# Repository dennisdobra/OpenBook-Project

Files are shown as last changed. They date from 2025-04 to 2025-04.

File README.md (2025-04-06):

# 📖 OpenBook ESP32-C6 – Hardware Overview & Pin Connections

This document describes the **hardware functionality**, **pin mappings**, and **key components** of the OpenBook e-reader, based on the ESP32-C6-WROOM-1-N8 microcontroller.

## 🛠️ Implementation Steps

1. **Schematic Design** – Created in Eagle with all key modules (ESP32-C6, RTC, BME688, etc.).

2. **2D PCB Layout** – Components placed with routing efficiency in mind.

3. **Signal Routing** – Manual routing of SPI, I²C, USB; verified differential pairs.

4. **GND Plane** – Full ground pour on both layers for EMI reduction.

5. **Power Net Classes** – Separate nets for VBAT, VUSB, and 3V3 with wider traces.

6. **Custom Rules** – DRC settings for clearance, trace width, via sizes uploaded.

7. **3D Models** – Designed from datasheets for battery, screen, and connectors.

---

## 🔧 Hardware Overview

### 🧠 Main Controller – ESP32-C6-WROOM-1-N8

- **Architecture**: RISC-V (Single-Core)
- **Wireless**: Wi-Fi 6, Bluetooth 5 LE
- **Operating Voltage**: 3.3V
- **Interfaces**: SPI, I²C, UART, GPIO, USB

---

## 💾 Storage & Display

### 📁 SD Card
- **Interface**: SPI
- **Pins**:
  - CS (SS_SD): `GPIO 4`
  - MOSI: `GPIO 7`
  - MISO: `GPIO 2`
  - SCK: `GPIO 6`

### 🖼️ E-Paper Display
- **Interface**: SPI (shared with SD)
- **Pins**:
  - CS (EPD_CS): `GPIO 10`
  - DC (EPD_DC): `GPIO 5`
  - RESET: `GPIO 23`
  - BUSY: `GPIO 3` *(shared with MISO)*
  - MOSI / SCK: shared with SD

### 💾 External NOR Flash (64MB)
- **Interface**: SPI (shared)
- **Pins**:
  - CS (FLASH_CS): `GPIO 12`
  - Shared: `MOSI`, `MISO`, `SCK`

---

## ⏱️ Timekeeping & Sensors

### 🕒 RTC – DS3231SN
- **Interface**: I²C
- **Pins**:
  - SCL: `GPIO 22`
  - SDA: `GPIO 21`
  - INT: `GPIO 8`
  - 32KHz: `GPIO 1`
  - RESET: `GPIO 18`

### 🌡️ Environmental Sensor – BME688
- **Interface**: I²C (shared with RTC)
- **Supply Voltage**: 3.3V

---

## 🔋 Power Management

### ⚡ Power Supply
- **Input**: USB-C (5V)
- **Output**: 3.3V via LDO regulator
- **Protections**:
  - Reverse polarity diode
  - TVS diodes on USB & SPI lines

### 🔌 Charging Circuit – TP4056
- **Function**: Li-Po battery charging
- **Battery Monitoring**:
  - Gauge via I²C
  - Pins: `GPIO 19` (SCL), `GPIO 20` (SDA)

---

## 🖧 Communication & Interfaces

### 🔌 USB-C Connector
- **Data Pins**:
  - USB_D+: `GPIO 13`
  - USB_D-: `GPIO 12` *(shared with FLASH_CS)*

### 🔗 Qwiic / Stemma QT Connector
- **Interface**: I²C
- **Usage**: Plug-and-play I²C sensors

---

## ⏺️ User Inputs

- **BOOT Button**: `GPIO 9`
- **RESET Button**: connected to EN pin
- **CHANGE Button**: `GPIO 23`

---

## 🛡️ Protection Features

- TVS diodes on:
  - USB data lines
  - SPI lines (SD, Flash, Display)
- Diode-based reverse polarity protection

---

## 🧩 Communication Overview

| Peripheral | Interface | GPIO Pins Used |
|---|---|---|
| SD Card | SPI | GPIO 2, 4, 6, 7 |
| E-Paper Display | SPI | GPIO 3, 5, 10, 23 |
| External NOR Flash | SPI | GPIO 12, shared MOSI/MISO/SCK |
| RTC + BME688 | I²C | GPIO 1, 8, 18, 21, 22 |
| Battery Gauge | I²C | GPIO 19 (SCL), GPIO 20 (SDA) |
| USB-C Data | USB | GPIO 12 (D-), GPIO 13 (D+) |
| Buttons | GPIO | GPIO 9 (BOOT), GPIO 23 (CHANGE), EN |

---

## 📦 Bill of Materials (BOM)

| Componenta | Link | Preț estimativ |
|---|---|---|
| CHG_LED | [KP-1608SURCK - Kingbright](https://www.snapeda.com/parts/KP-1608SURCK/Kingbright/view-part/?ref=search&t=LED%200603) | 0.15€ |
| SJ1 | [Solder Jumpers](https://grabcad.com/library/solder-jumpers-1) | 0.05€ |
| R3 | [R0402 1% 100K (RC0402FR-07100KL) - YAGEO](https://componentsearchengine.com/part-view/R0402%201%25%20100%20K%20(RC0402FR-07100KL)/YAGEO) | 0.01€ |
| R1_PWRUSB | [R0402 1% 100K (RC0402FR-07100KL) - YAGEO](https://componentsearchengine.com/part-view/R0402%201%25%20100%20K%20(RC0402FR-07100KL)/YAGEO) | 0.01€ |
| C1, C2, C4_USB, C6, C7, C8, C9, C10, C_DELAY | [CC0402MRX5R5BB106 - YAGEO](https://componentsearchengine.com/part-view/CC0402MRX5R5BB106/YAGEO) | 0.10€ (per unitate) |
| C3 | [Link 3D model](https://a360.co/4iZy6AA) | 0.12€ |
| R1_PINH1, R2-PINH1, R_BOOT, R_CHARGE, R_CL1, R_RESET | [R0402 1% 100K (RC0402FR-07100KL) - YAGEO](https://componentsearchengine.com/part-view/R0402%201%25%20100%20K%20(RC0402FR-07100KL)/YAGEO) | 0.01€ (per unitate) |
| R1, R1-PINH, R2-PINH, R4, R5, R6, R7, R8, R9, R10 | [R0402 1% 100K (RC0402FR-07100KL) - YAGEO](https://componentsearchengine.com/part-view/R0402%201%25%20100%20K%20(RC0402FR-07100KL)/YAGEO) | 0.01€ (per unitate) |
| J4 | [Store Comet SRL](https://store.comet.srl.ro/Catalogue/Product/43497/) | 0.35€ |
| R_CAPACITOR | [R0402 1% 100K (RC0402FR-07100KL) - YAGEO](https://componentsearchengine.com/part-view/R0402%201%25%20100%20K%20(RC0402FR-07100KL)/YAGEO) | 0.01€ |
| C5 | [CC0402MRX5R5BB106 - YAGEO](https://componentsearchengine.com/part-view/CC0402MRX5R5BB106/YAGEO) | 0.10€ |
| EPD_C1, EPD_C2, EPD_C5, EPD_C6, EPD_C7, EPD_C8, EPD_C9, EPD_C10, EPD_C11, EPD_C12 | [CC0402MRX5R5BB106 - YAGEO](https://componentsearchengine.com/part-view/CC0402MRX5R5BB106/YAGEO) | 0.10€ (per unitate) |
| R2 | [R0402 1% 100K (RC0402FR-07100KL) - YAGEO](https://componentsearchengine.com/part-view/R0402%201%25%20100%20K%20(RC0402FR-07100KL)/YAGEO) | 0.01€ |
| R1_BAT | [R0402 1% 100K (RC0402FR-07100KL) - YAGEO](https://componentsearchengine.com/part-view/R0402%201%25%20100%20K%20(RC0402FR-07100KL)/YAGEO) | 0.01€ |
| Q1, Q3 | [SI1308EDL-T1-GE3 - Vishay](https://componentsearchengine.com/part-view/SI1308EDL-T1-GE3/Vishay) | 0.45€ (per unitate) |
| R2_BAT | [R0402 1% 100K (RC0402FR-07100KL) - YAGEO](https://componentsearchengine.com/part-view/R0402%201%25%20100%20K%20(RC0402FR-07100KL)/YAGEO) | 0.01€ |
| C1_BAT, C1_BAT1, C1_BAT2, C2_BAT, C5_USB | [CC0402MRX5R5BB106 - YAGEO](https://componentsearchengine.com/part-view/CC0402MRX5R5BB106/YAGEO) | 0.10€ (per unitate) |
| C4 | [CC0402MRX5R5BB106 - YAGEO](https://componentsearchengine.com/part-view/CC0402MRX5R5BB106/YAGEO) | 0.10€ |
| R2-USB, R2-USB1 | [R0402 1% 100K (RC0402FR-07100KL) - YAGEO](https://componentsearchengine.com/part-view/R0402%201%25%20100%20K%20(RC0402FR-07100KL)/YAGEO) | 0.01€ (per unitate) |
| L1 | [744043680 - Wurth Elektronik](https://eu.mouser.com/ProductDetail/Wurth-Elektronik/744043680?qs=PGXP4M47uW6VkZq%252BkzjrHA%3D%3D) | 0.85€ |
| IC1 | [BD5229G-TR - ROHM Semiconductor](https://componentsearchengine.com/part-view/BD5229G-TR/ROHM%20Semiconductor) | 1.20€ |
| BOOT_BUTTON, CHANGE_BUTTON, RESET_BUTTON | [EVQP7L01P - Panasonic](https://www.snapeda.com/parts/EVQP7L01P/Panasonic/view-part/?ref=search&t=evqp7l) | 0.25€ (per unitate) |
| C10_SUPERCAP | [CPH3225A - Seiko Instruments](https://www.snapeda.com/api/url_track_click_mouser/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) | 2.50€ |
| U3 | [DS3231SN - Analog Devices](https://www.snapeda.com/api/url_track_click_mouser/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) | 8.95€ |
| U2 | [ESP32-C6-WROOM-1-N8 - Espressif](https://www.snapeda.com/parts/ESP32-C6-WROOM-1-N8/Espressif+Systems/view-part/?ref=eda) | 4.50€ |
| PFMF.050.1 | [B72520T0350K062 - EPCOS-TDK](https://www.mouser.co.uk/ProductDetail/EPCOS-TDK/B72520T0350K062?qs=dEfas%2FXlABIszF52uu7vrg%3D%3D) | 0.65€ |
| D2, D7 | [SD0805S020S1R0 - KYOCERA-AVX](https://eu.mouser.com/ProductDetail/KYOCERA-AVX/SD0805S020S1R0?qs=jCA%252BPfw4LHbpkAoSnwrdjw%3D%3D) | 0.30€ (per unitate) |
| SENSOR2 | [BME680 - Bosch](https://www.snapeda.com/parts/BME680/Bosch/view-part/?welcome=home) | 10.50€ |
| MCP73831 | [MCP73831T-2ACI-OT - Microchip](https://www.digikey.ro/en/products/detail/microchip-technology/MCP73831T-2ACI-OT/964301) | 0.75€ |
| J1 | [XC6220A331MR-G - Torex](https://componentsearchengine.com/part-view/XC6220A331MR-G/Torex) | 1.25€ |
| U4 | [MAX17048G+T10 - Analog Devices](https://www.snapeda.com/api/url_track_click_mouser/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) | 3.80€ |
| D3, D4, D5 | [MBR0530 - ON Semiconductor](https://www.snapeda.com/api/url_track_click_mouser/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) | 0.40€ (per unitate) |
| D6, D8, D9, D10, D11, D12 | [PGB1010603MR - Littelfuse](https://www.snapeda.com/api/url_track_click_mouser/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) | 0.30€ (per unitate) |
| J3 | [Model Link - DigiKey](https://www.digikey.ro/en/models/926710) | 1.05€ |
| J2 | [USB4110-GF-A - GCT](https://componentsearchengine.com/part-view/USB4110-GF-A/GCT%20(GLOBAL%20CONNECTOR%20TECHNOLOGY)) | 0.95€ |
| Q2 | [DMG2305UX-7 - Diodes Inc](https://componentsearchengine.com/part-view/DMG2305UX-7/Diodes%20Incorporated) | 0.55€ |
| TP1, TP2, TP3, TP4, TP5, TP6, TP7, TP8, TP9, TP10, TP11, TP12, TP13, TP14, TP15, TP16, TP17 | [Test Points PCB](https://grabcad.com/library/test-points-printed-circuit-board-1) | 0.02€ (per unitate) |
| D1 | [USBLC6-2SC6Y - STMicroelectronics](https://www.snapeda.com/parts/USBLC6-2SC6Y/STMicroelectronics/view-part/?ref=eda) | 0.60€ |
| U1 | [W25Q512JVEIQ - Winbond](https://www.snapeda.com/parts/W25Q512JVEIQ/Winbond+Electronics/view-part/?ref=eda) | 4.20€ |
| IC4 | [XC6220A331MR-G - Torex](https://componentsearchengine.com/part-view/XC6220A331MR-G/Torex) | 1.25€ |

## 📌 Pin Assignments

| ESP32-C6 Pin | Function | Connected To | Description |
|---|---|---|---|
| 3 | RESET | Reset Button | System hardware reset |
| 4 | SS_SD | SD Card (pin 2) | SPI Slave Select for SD card |
| 6 | SCK | SD Card (pin 5) | SPI Clock signal |
| 7 | MOSI | SD Card (pin 3) | SPI Master Out Slave In |
| 8 | INT_RTC | RTC Module (pin 3) | Interrupt signal from RTC |
| 9 | 32KHz | RTC Module (pin 1) | 32KHz clock signal from RTC |
| 13 | USB_D- | USB-C Connector (pin 3) | USB Data Negative line |
| 14 | USB_D+ | USB-C Connector (pin 1) | USB Data Positive line |
| 15 | IO/BOOT | Boot Button | Boot mode selector button |
| 16 | RTC_RST | RTC Module (pin 4) | RTC reset control |
| 17 | I2C_PW | BME688 Sensor (pins 6, 8, 2) | Power control for environmental sensor |
| 19 | SDA | Multiple I²C devices | I²C Serial Data line (shared) |
| 20 | SCL | Multiple I²C devices | I²C Serial Clock line (shared) |
| 23 | IO/CHANGE | Change Button | Display/Mode change button |
| 27 | MISO | SD Card (pin 7) | SPI Master In Slave Out |

---

# Circuit Block Diagram

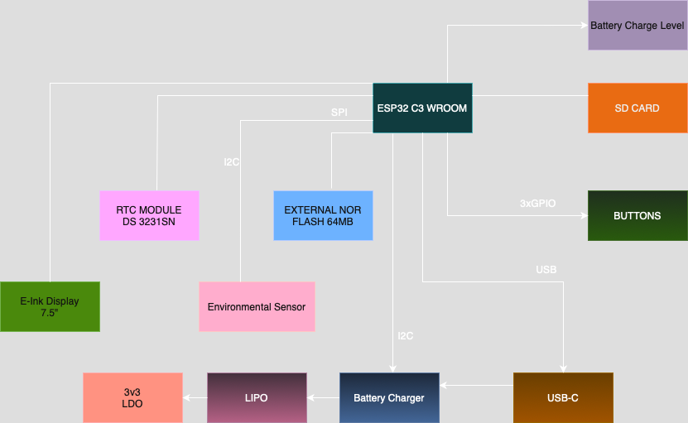
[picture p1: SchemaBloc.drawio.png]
Circuit Block Diagram


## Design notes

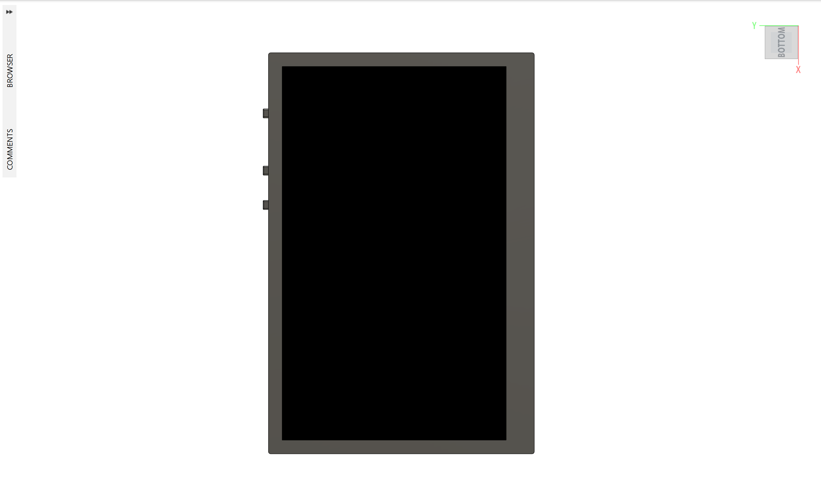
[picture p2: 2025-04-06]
Images/Display1.png

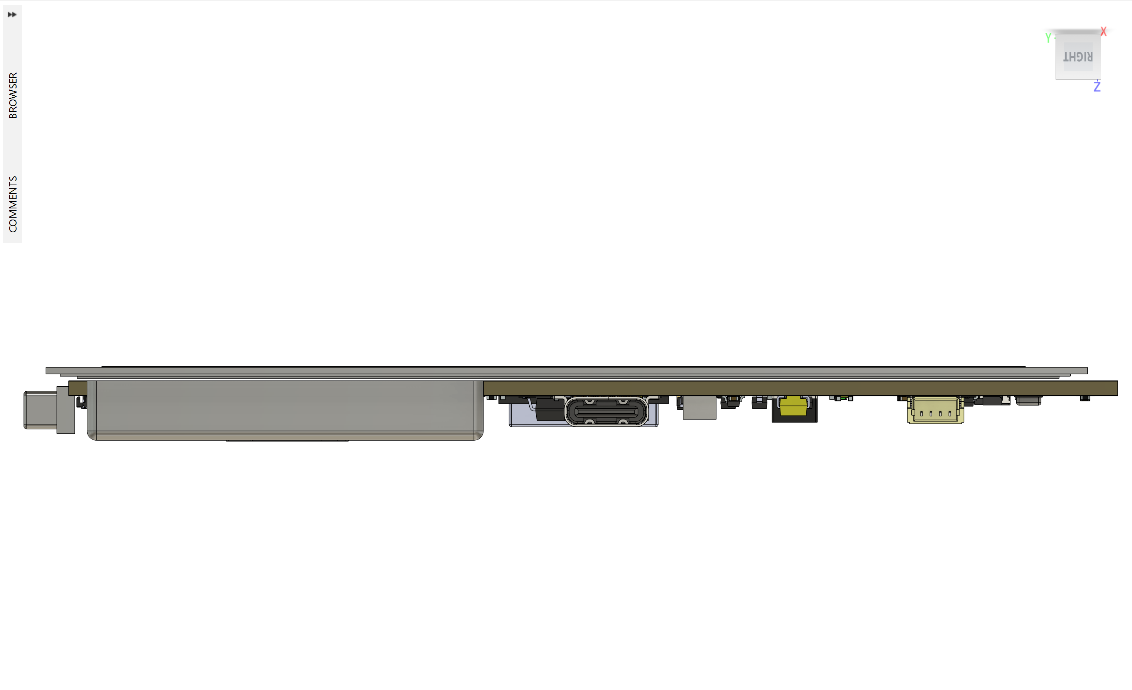
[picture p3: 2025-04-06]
Images/Side_View1.png

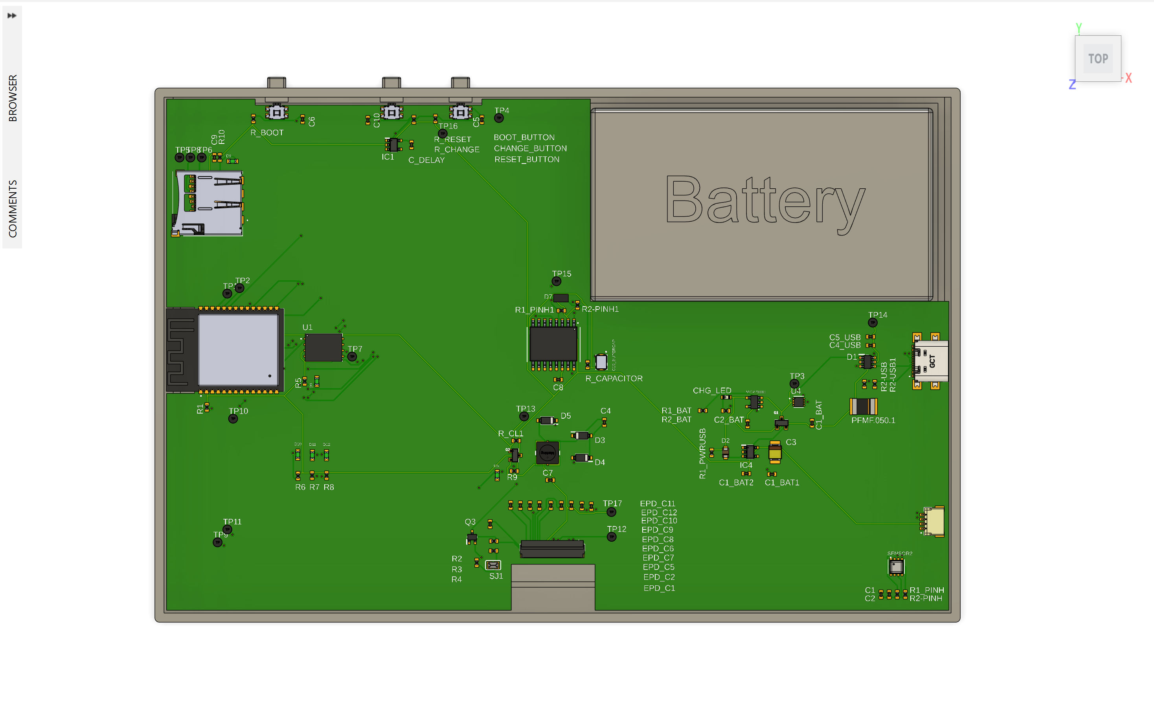
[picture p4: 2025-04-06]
Images/Board1.png

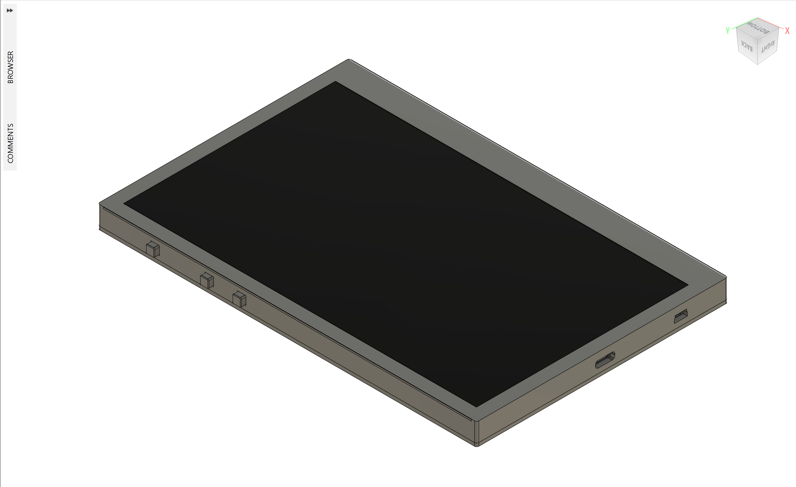
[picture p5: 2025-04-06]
Images/Display2.png

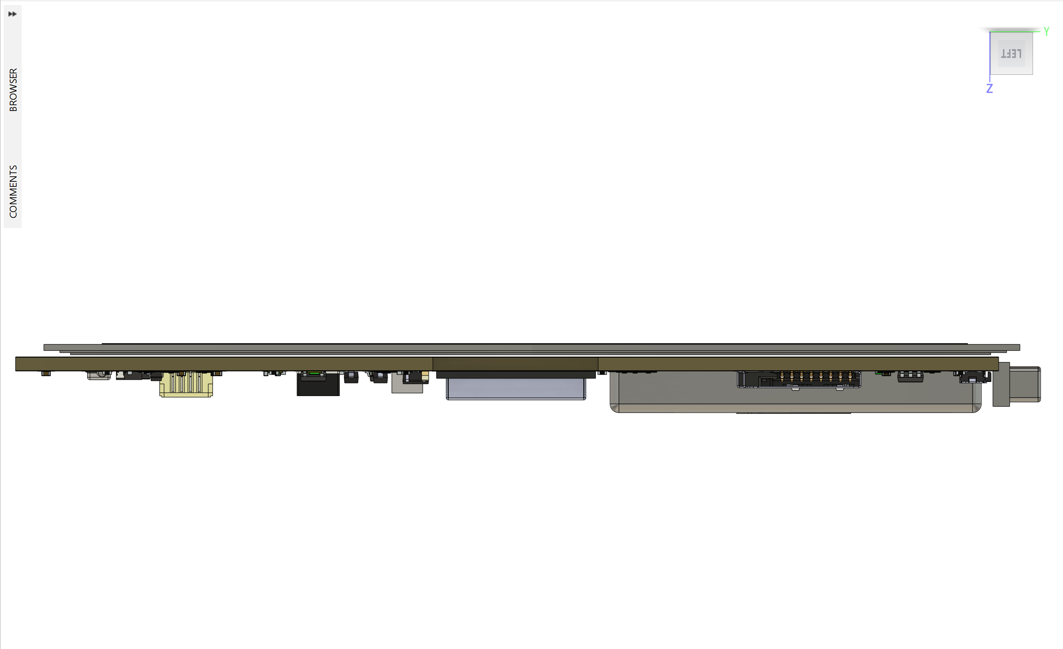
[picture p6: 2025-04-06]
Images/Side_View2.png

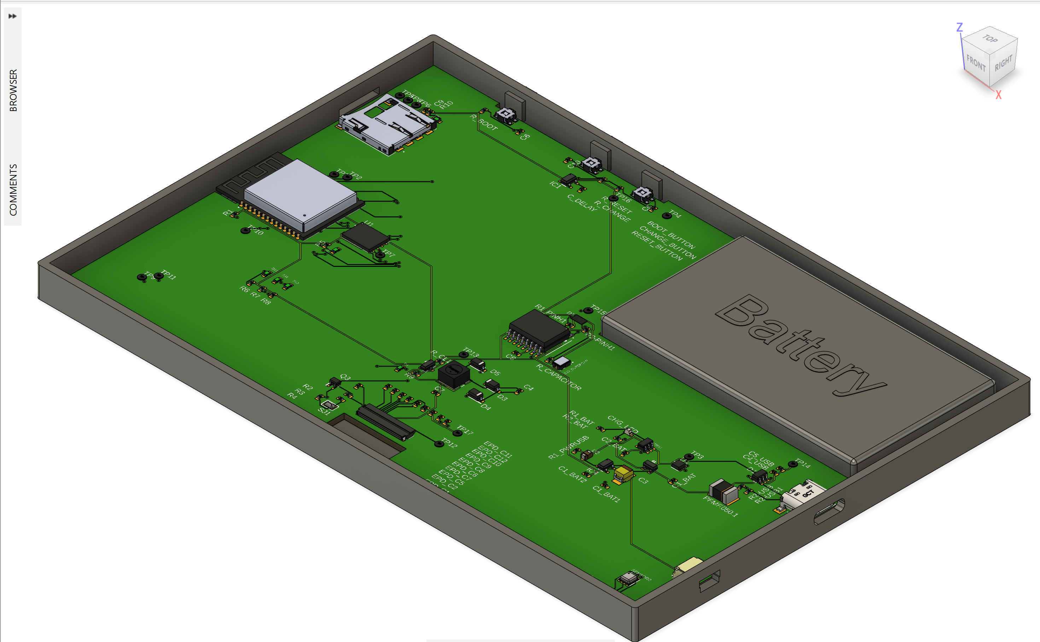
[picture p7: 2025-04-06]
Images/Board2.png

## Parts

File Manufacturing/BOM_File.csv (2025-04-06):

Qty | Value | Device | Package | Parts | Description | ARROW_PART_NUMBER | ARROW_PRICE-STOCK | AVAILABILITY | CENTROID_NOT_SPECIFIED | CHECK_PRICES | COPYRIGHT | DATASHEET | DESCRIPTION | DIGIKEY_DESCRIPTION | DIGIKEY_PART_NUMBER | HEIGHT | LEAD_FREE | MANUFACTURER_NAME | MANUFACTURER_PART_NUMBER | MF | MFR_NAME | MOUSER_PART_NUMBER | MOUSER_PRICE-STOCK | MOUSER_TESTING_PART_NUMBER | MOUSER_TESTING_PRICE-STOCK | MP | MPN | PACKAGE | POPULARITY | PREFIX | PRICE | PROD_ID | PURCHASE-URL | ROHS | SNAPEDA_LINK | SPICEMODEL | SPICEPREFIX | TEMPERATURE_RANGE_HIGH | TEMPERATURE_RANGE_LOW | TP_SIGNAL_NAME | VALUE,,,,,,,,,,,,,,,,
1 |  | ADAFRUIT_LEDCHIP-LED0603 | ADAFRUIT_CHIP-LED0603 | CHG_LED | LED |  |  |  |  |  |  |  |  |  |  |  |  |  |  |  |  |  |  |  |  |  |  |  |  |  |  |  |  |  | https://www.snapeda.com/parts/KP-1608SURCK/Kingbright/view-part/?ref=search&t=LED%200603 |  |  |  |  |  | ,,,,,,,,,,,,,,,,
1 |  | SJ | SJ | SJ1 | SMD solder JUMPER |  |  |  |  |  |  |  |  |  |  |  |  |  |  |  |  |  |  |  |  |  |  |  | 3 |  |  |  | https://grabcad.com/library/solder-jumpers-1 |  |  |  |  |  |  |  | ,,,,,,,,,,,,,,,,
1 | 0.47 | ESP32_WROVER_EAGLE-LTSPICE_RR0402 | ESP32_WROVER_EAGLE-LTSPICE_R0402 | R3 | RESISTOR, European symbol |  |  |  |  |  |  |  |  |  |  |  |  |  |  |  |  |  |  |  |  |  |  |  |  |  |  |  | https://componentsearchengine.com/part-view/R0402%201%25%20100%20K%20(RC0402FR-07100KL)/YAGEO |  |  | NONE | R |  |  |  | ,,,,,,,,,,,,,,,
1 | 100k | ESP32_WROVER_EAGLE-LTSPICE_RR0402 | ESP32_WROVER_EAGLE-LTSPICE_R0402 | R1_PWRUSB | RESISTOR, European symbol |  |  |  |  |  |  |  |  |  |  |  |  |  |  |  |  |  |  |  |  |  |  |  |  |  |  |  | https://componentsearchengine.com/part-view/R0402%201%25%20100%20K%20(RC0402FR-07100KL)/YAGEO |  |  | NONE | R |  |  |  | ,,,,,,,,,,,,,,,
9 | 100nF | EAGLE-LTSPICE_CC0402 | EAGLE-LTSPICE_C0402 | C1, C2, C4_USB, C6, C7, C8, C9, C10, C_DELAY | CAPACITOR, European symbol |  |  |  |  |  |  |  |  |  |  |  |  |  |  |  |  |  |  |  |  |  |  |  |  |  |  |  | https://componentsearchengine.com/part-view/CC0402MRX5R5BB106/YAGEO |  |  | NONE | C |  |  |  | ,,,,,,,
1 | 100uF TANT | RCL_CPOL-EUCT3528 | RCL_CT3528 | C3 | POLARIZED CAPACITOR, European symbol |  |  |  |  |  |  |  |  |  |  |  |  |  |  |  |  |  |  |  |  |  |  |  | 0 |  |  |  | https://a360.co/4iZy6AA |  |  |  | C |  |  |  | ,,,,,,,,,,,,,,,
6 | 10K | ESP32_WROVER_EAGLE-LTSPICE_RR0402 | ESP32_WROVER_EAGLE-LTSPICE_R0402 | R1_PINH1, R2-PINH1, R_BOOT, R_CHARGE, R_CL1, R_RESET | RESISTOR, European symbol |  |  |  |  |  |  |  |  |  |  |  |  |  |  |  |  |  |  |  |  |  |  |  |  |  |  |  | https://componentsearchengine.com/part-view/R0402 1% 100 K (RC0402FR-07100KL)/YAGEO |  |  | NONE | R |  |  |  | ,,,,,,,,,,
10 | 10k | ESP32_WROVER_EAGLE-LTSPICE_RR0402 | ESP32_WROVER_EAGLE-LTSPICE_R0402 | R1, R1-PINH, R2-PINH, R4, R5, R6, R7, R8, R9, R10 | RESISTOR, European symbol |  |  |  |  |  |  |  |  |  |  |  |  |  |  |  |  |  |  |  |  |  |  |  |  |  |  |  | https://componentsearchengine.com/part-view/R0402 1% 100 K (RC0402FR-07100KL)/YAGEO |  |  | NONE | R |  |  |  | ,,,,,,
1 | 112A-TAAR-R03_ATTEND | 112A-TAAR-R03_ATTEND | 112ATAARR03ATTEND | J4 | Micro SD Card Socket, Push-Push Type, Top Mount, SMT, H=1.83mm, 10u |  |  |  |  |  |  |  | Micro SD Card Socket | Push-Push Type | Top Mount | SMT | H=1.83mm | 10u |  |  | 1.9mm |  | ATTEND | 112A-TAAR-R03 ATTEND |  |  |  |  |  |  |  |  | https://store.comet.srl.ro/Catalogue/Product/43497/ |  |  |  |  |  |  |  | ,,,,,,,,,,,
1 | 15 | ESP32_WROVER_EAGLE-LTSPICE_RR0402 | ESP32_WROVER_EAGLE-LTSPICE_R0402 | R_CAPACITOR | RESISTOR, European symbol |  |  |  |  |  |  |  |  |  |  |  |  |  |  |  |  |  |  |  |  |  |  |  |  |  |  |  | https://componentsearchengine.com/part-view/R0402%201%25%20100%20K%20(RC0402FR-07100KL)/YAGEO |  |  | NONE | R |  |  |  | ,,,,,,,,,,,,,,,
1 | 1uF | EAGLE-LTSPICE_CC0402 | EAGLE-LTSPICE_C0402 | C5 | CAPACITOR, European symbol |  |  |  |  |  |  |  |  |  |  |  |  |  |  |  |  |  |  |  |  |  |  |  |  |  |  |  | https://componentsearchengine.com/part-view/CC0402MRX5R5BB106/YAGEO |  |  | NONE | C |  |  |  | ,,,,,,,,,,,,,,,
10 | 1uF/50V | ESP32_WROVER_EAGLE-LTSPICE_CC0402 | ESP32_WROVER_EAGLE-LTSPICE_C0402 | EPD_C1, EPD_C2, EPD_C5, EPD_C6, EPD_C7, EPD_C8, EPD_C9, EPD_C10, EPD_C11, EPD_C12 | CAPACITOR, European symbol |  |  |  |  |  |  |  |  |  |  |  |  |  |  |  |  |  |  |  |  |  |  |  |  |  |  |  | https://componentsearchengine.com/part-view/CC0402MRX5R5BB106/YAGEO |  |  | NONE | C |  |  |  | ,,,,,,
1 | 2.2 | ESP32_WROVER_EAGLE-LTSPICE_RR0402 | ESP32_WROVER_EAGLE-LTSPICE_R0402 | R2 | RESISTOR, European symbol |  |  |  |  |  |  |  |  |  |  |  |  |  |  |  |  |  |  |  |  |  |  |  |  |  |  |  | https://componentsearchengine.com/part-view/R0402%201%25%20100%20K%20(RC0402FR-07100KL)/YAGEO |  |  | NONE | R |  |  |  | ,,,,,,,,,,,,,,,
1 | 200 | ESP32_WROVER_EAGLE-LTSPICE_RR0402 | ESP32_WROVER_EAGLE-LTSPICE_R0402 | R1_BAT | RESISTOR, European symbol |  |  |  |  |  |  |  |  |  |  |  |  |  |  |  |  |  |  |  |  |  |  |  |  |  |  |  | https://componentsearchengine.com/part-view/R0402%201%25%20100%20K%20(RC0402FR-07100KL)/YAGEO |  |  | NONE | R |  |  |  | ,,,,,,,,,,,,,,,
2 | 20V/4.2A/52mΩ/1.4W | ESP32_WROVER_SPARKFUN-DISCRETESEMI_MOSFET_PCH-DMG2305UX-7 | ESP32_WROVER_SPARKFUN-DISCRETESEMI_SOT23-3 | Q1, Q3 | P-channel MOSFETs |  |  |  |  |  |  |  |  |  |  |  |  |  |  |  |  |  |  |  |  |  |  |  |  |  |  | TRAN-14388 | https://componentsearchengine.com/part-view/SI1308EDL-T1-GE3/Vishay |  |  |  |  |  |  |  | 20V/4.2A/52mΩ/1.4W,,,,,,,,,,,,,,,
1 | 2K | ESP32_WROVER_EAGLE-LTSPICE_RR0402 | ESP32_WROVER_EAGLE-LTSPICE_R0402 | R2_BAT | RESISTOR, European symbol |  |  |  |  |  |  |  |  |  |  |  |  |  |  |  |  |  |  |  |  |  |  |  |  |  |  |  | https://componentsearchengine.com/part-view/R0402%201%25%20100%20K%20(RC0402FR-07100KL)/YAGEO |  |  | NONE | R |  |  |  | ,,,,,,,,,,,,,,,
5 | 4.7uF | EAGLE-LTSPICE_CC0402 | EAGLE-LTSPICE_C0402 | C1_BAT, C1_BAT1, C1_BAT2, C2_BAT, C5_USB | CAPACITOR, European symbol |  |  |  |  |  |  |  |  |  |  |  |  |  |  |  |  |  |  |  |  |  |  |  |  |  |  |  | https://componentsearchengine.com/part-view/CC0402MRX5R5BB106/YAGEO |  |  | NONE | C |  |  |  | ,,,,,,,,,,,
1 | 4.7uF/25V | EAGLE-LTSPICE_CC0402 | EAGLE-LTSPICE_C0402 | C4 | CAPACITOR, European symbol |  |  |  |  |  |  |  |  |  |  |  |  |  |  |  |  |  |  |  |  |  |  |  |  |  |  |  | https://componentsearchengine.com/part-view/CC0402MRX5R5BB106/YAGEO |  |  | NONE | C |  |  |  | ,,,,,,,,,,,,,,,
2 | 5k1 | ESP32_WROVER_EAGLE-LTSPICE_RR0402 | ESP32_WROVER_EAGLE-LTSPICE_R0402 | R2-USB, R2-USB1 | RESISTOR, European symbol |  |  |  |  |  |  |  |  |  |  |  |  |  |  |  |  |  |  |  |  |  |  |  |  |  |  |  | https://componentsearchengine.com/part-view/R0402%201%25%20100%20K%20(RC0402FR-07100KL)/YAGEO |  |  | NONE | R |  |  |  | ,,,,,,,,,,,,,,
1 | 68uH | 744043680IND_4828-WE-TPC_WRE | IND_4828-WE-TPC_WRE | L1 |  |  |  |  |  |  | Copyright (C) 2024 Ultra Librarian. All rights reserved. |  |  |  |  |  |  |  | 744043680 |  | Wurth Electronics |  |  |  |  |  |  |  |  |  |  |  | https://eu.mouser.com/ProductDetail/Wurth-Elektronik/744043680?qs=PGXP4M47uW6VkZq%252BkzjrHA%3D%3D |  |  |  |  |  |  |  | ,,,,,,,,,,,,,,,,
1 | BD5229G-TR | BD5229G-TR | SOT95P280X125-5N | IC1 | Voltage Detector with Adjustable Delay Time: CMOS processes are utilized to develop high precision, low current consumption CMOS reset ICs that allow arbitrary setting of the delay time. The extensive lineup includes both Nch Open Drain and CMOS output types in a wide range of detection voltages (from 2.3V to 6.0V, in 0.1V steps), enabling selection of the ideal solution based on customer requirements. In addition, the entire series is of course both lead-free and RoHS-compliant. |  |  |  |  |  |  |  | Voltage Detector with Adjustable Delay Time: CMOS processes are utilized to develop high precision | low current consumption CMOS reset ICs that allow arbitrary setting of the delay time. The extensive lineup includes both Nch Open Drain and CMOS output types in a wide range of detection voltages (from 2.3V to 6.0V | in 0.1V steps) | enabling selection of the ideal solution based on customer requirements. In addition | the entire series is of course both lead-free and RoHS-compliant. |  |  | 1.25mm |  | ROHM Semiconductor | BD5229G-TR |  |  | 755-BD5229G-TR | https://www.mouser.co.uk/ProductDetail/ROHM-Semiconductor/BD5229G-TR?qs=4kLU8WoGk0vvnhrrYwdszw%3D%3D |  |  |  |  |  | https://componentsearchengine.com/part-view/BD5229G-TR/ROHM%20Semiconductor |  |  |  |  |  |  |  | ,,,,,,,,,,,,
3 | BUTTON_CUSYOMV1 | BUTTON_CUSYOMV1 | MYBUTTON | BOOT_BUTTON, CHANGE_BUTTON, RESET_BUTTON |  |  |  |  |  |  |  |  |  |  |  |  |  |  |  |  |  |  |  |  |  |  |  |  |  |  |  |  | https://www.snapeda.com/parts/EVQP7L01P/Panasonic/view-part/?ref=search&t=evqp7l |  |  |  |  |  |  |  | ,,,,,,,,,,,,,,
1 | CPH3225A | CPH3225A | CAPCP3225X100N | C10_SUPERCAP | Cap 0.011F 3.3V 1210 Flat Check availability |  |  | Not in stock |  | https://www.snapeda.com/parts/CPH3225A/Seiko+Instruments/view-part/?ref=eda |  |  | 11 mF (EDLC) Supercapacitor 3.3 V 1210 (3225 Metric) - - |  |  |  |  |  |  | Seiko Instruments |  |  |  |  |  | CPH3225A |  | 1210 Seiko |  |  | None |  | https://www.snapeda.com/api/url_track_click_mouser/?unipart_id=562593&manufacturer=Seiko Instruments&part_name=CPH3225A&search_term=None |  | https://www.snapeda.com/parts/CPH3225A/Seiko+Instruments/view-part/?ref=snap |  |  |  |  |  | ,,,,,,,,,,,,,,,,
1 | DS3231SN# | DS3231SN# | SOIC127P1032X265-16N | U3 | Real Time Clock Serial 16-Pin SOIC W T/R Check availability |  |  | In Stock |  | https://www.snapeda.com/parts/DS3231SN%23/Analog+Devices/view-part/?ref=eda |  |  | Extremely Accurate I²C-Integrated RTC/TCXO/Crystal |  |  |  |  |  |  | Analog Devices |  |  |  |  |  | DS3231SN# |  | SOIC-16 Maxim |  |  | None |  | https://www.snapeda.com/api/url_track_click_mouser/?unipart_id=99048&manufacturer=Analog Devices&part_name=DS3231SN#&search_term=None |  | https://www.snapeda.com/parts/DS3231SN%23/Analog+Devices/view-part/?ref=snap |  |  |  |  |  | ,,,,,,,,,,,,,,,,
1 | ESP32-C6-WROOM-1-N8 | ESP32-C6-WROOM-1-N8 | XCVR_ESP32-C6-WROOM-1-N8 | U2 | Check availability |  |  | In Stock |  | https://www.snapeda.com/parts/ESP32-C6-WROOM-1-N8/Espressif+Systems/view-part/?ref=eda |  |  | Multiprotocol Modules ESP32-C6 module | Wi-Fi 6 in 2.4 GHz band | Bluetooth 5 | Zigbee 3.0 and Thread. ESP34-WROOM Compatible - ENGINEERING SAMPLE |  |  |  |  |  |  | Espressif Systems |  |  |  |  |  | ESP32-C6-WROOM-1-N8 |  | None |  | https://www.snapeda.com/parts/ESP32-C6-WROOM-1-N8/Espressif+Systems/view-part/?ref=eda | None |  |  |  | https://www.snapeda.com/parts/ESP32-C6-WROOM-1-N8/Espressif+Systems/view-part/?ref=snap |  |  | ,,,,,,,,,,,,,,,,
1 | ESP32C6_VARISTORCN1812 | ESP32C6_VARISTORCN1812 | ESP32C6_VARISTOR_CT/CN1812 | PFMF.050.1 | VARISTOR |  |  |  |  |  |  |  |  |  |  |  |  |  |  |  |  |  |  |  |  |  |  |  | 0 |  |  |  | https://www.mouser.co.uk/ProductDetail/EPCOS-TDK/B72520T0350K062?qs=dEfas%2FXlABIszF52uu7vrg%3D%3D |  |  |  |  |  |  |  | ,,,,,,,,,,,,,,,,
2 | ESP32_WROVER_AVX---SD0805S020S1R0_AVX_SD0805S020S1R0_0_0AVX_SD0805S020S1R0_0_0 | ESP32_WROVER_AVX---SD0805S020S1R0_AVX_SD0805S020S1R0_0_0AVX_SD0805S020S1R0_0_0 | ESP32_WROVER_AVX---SD0805S020S1R0_AVX_SD0805S020S1R0_0 | D2, D7 | Schottky Barrier Rectifier Diode |  |  |  | No |  |  | http://datasheets.avx.com/schottky.pdf |  | DIODE SCHOTTKY 20V 1A 0805 | 478-7800-1-ND |  | yes |  |  | AVX |  | 581-SD0805S020S1R0 |  |  |  |  |  | 0805 (2012 metric) |  | D |  |  | https://eu.mouser.com/ProductDetail/KYOCERA-AVX/SD0805S020S1R0?qs=jCA%252BPfw4LHbpkAoSnwrdjw%3D%3D | yes |  |  |  | +125°C | -55°C |  | ,,,,,,,,,,,,,,,
1 | ESP32_WROVER_BME680_BME680 | ESP32_WROVER_BME680_BME680 | ESP32_WROVER_BME680_PSON80P300X300X100-8N | SENSOR2 | Integrated Environmental Unit |  |  | Unavailable |  |  |  |  | Integrated Environmental Unit |  |  |  |  |  |  | Bosch Sensortec |  |  |  |  |  | BME680 |  | LGA-8 Bosch Tools |  |  | None |  | https://www.snapeda.com/parts/BME680/Bosch/view-part/?welcome=home |  |  |  |  |  |  |  | ,,,,,,,,,,,,,,,,
1 | ESP32_WROVER_SPARKFUN-IC-POWER_MCP73831 | ESP32_WROVER_SPARKFUN-IC-POWER_MCP73831 | ESP32_WROVER_SPARKFUN-IC-POWER_SOT23-5 | MCP73831 | MCP73831T Li-Ion, Li-Pol Controller |  |  |  |  |  |  |  |  |  |  |  |  |  |  |  |  |  |  |  |  |  |  |  |  |  |  | IC-09995 | https://www.digikey.ro/en/products/detail/microchip-technology/MCP73831T-2ACI-OT/964301 |  |  |  |  |  |  |  | ,,,,,,,,,,,,,,,
1 | FH34SRJ-24S-0.5SH_99_ | FH34SRJ-24S-0.5SH_99_ | FH34SRJ24S05SH99 | J1 | (0.50mm) Surface Mount, Right Angle |  |  |  |  |  |  |  | 24 Position FFC | FPC Connector Contacts | (0.50mm) Surface Mount | Right Angle |  |  | 1.1mm |  | Hirose | FH34SRJ-24S-0.5SH(99) |  |  | 798-FH34SRJ24S05SH99 | https://www.mouser.co.uk/ProductDetail/Hirose-Connector/FH34SRJ-24S-0.5SH99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 |  |  |  |  |  |  | https://componentsearchengine.com/part-view/XC6220A331MR-G/Torex |  |  |  |  |  |  |  | ,,,,,,,,,,,,,,,
1 | MAX17048G+T10 | MAX17048G+T10 | SON50P200X200X80-9N | U4 | Check availability |  |  | In Stock |  | https://www.snapeda.com/parts/MAX17048G+T10/Analog+Devices/view-part/?ref=eda |  |  | 3µA 1-Cell/2-Cell Fuel Gauge with ModelGauge |  |  |  |  |  |  | Analog Devices |  |  |  |  |  | MAX17048G+T10 |  | TDFN-8 Maxim |  |  | None |  | https://www.snapeda.com/api/url_track_click_mouser/?unipart_id=329239&manufacturer=Analog Devices&part_name=MAX17048G+T10&search_term=None |  | https://www.snapeda.com/parts/MAX17048G+T10/Analog+Devices/view-part/?ref=snap |  |  |  |  |  | ,,,,,,,,,,,,,,,,
3 | MBR0530 | MBR0530 | SOD3716X135N | D3, D4, D5 | ON SEMICONDUCTOR - MBR0530 - DIODE, SCHOTTKY, 0.5A, 30V, SOD-123 |  |  | In Stock |  | https://www.snapeda.com/parts/MBR0530/Onsemi/view-part/?ref=eda |  |  | Diode Schottky 30 V 500mA Surface Mount SOD-123 |  |  |  |  |  |  | ON Semiconductor |  |  |  |  |  | MBR0530 |  | SOD-123-2 ON Semiconductor |  |  | None |  | https://www.snapeda.com/api/url_track_click_mouser/?unipart_id=179458&manufacturer=ON Semiconductor&part_name=MBR0530&search_term=None |  | https://www.snapeda.com/parts/MBR0530/Onsemi/view-part/?ref=snap |  |  |  |  |  | ,,,,,,,,,,
6 | PGB1010603MR | PGB1010603MR | DIOC1608X36N | D6, D8, D9, D10, D11, D12 | Check availability |  |  | In Stock |  | https://www.snapeda.com/parts/PGB1010603MR/Littelfuse/view-part/?ref=eda |  |  | 150V (Typ) Clamp - Ipp Tvs Diode Surface Mount 0603 (1608 Metric) |  |  |  |  |  |  | Littelfuse Inc. |  |  |  |  |  | PGB1010603MR |  | 0603 Littelfuse Inc. |  |  | None |  | https://www.snapeda.com/api/url_track_click_mouser/?unipart_id=5659453&manufacturer=Littelfuse Inc.&part_name=PGB1010603MR&search_term=None |  | https://www.snapeda.com/parts/PGB1010603MR/Littelfuse/view-part/?ref=snap |  |  |  |  |  | ,,,,,,,,,,,
1 | QWIIC_RIGHT_ANGLE | QWIIC_CONNECTORJS-1MM | JST04_1MM_RA | J3 | SparkFun I2C Standard Qwiic Connector |  |  |  |  |  |  |  |  |  |  |  |  |  |  |  |  |  |  |  |  |  |  |  |  |  |  | CONN-13694 | https://www.digikey.ro/en/models/926710 |  |  |  |  |  |  |  | QWIIC_RIGHT_ANGLE,,,,,,,,,,,,,,,,
1 | SAMACSYS_PARTS_USB4110-GF-A | SAMACSYS_PARTS_USB4110-GF-A | SAMACSYS_PARTS_USB4110GFA | J2 | CONN USB 2.0 TYPE-C R/A SMT |  |  |  |  |  |  |  | CONN USB 2.0 TYPE-C R/A SMT |  |  | 3.26mm |  | GCT (GLOBAL CONNECTOR TECHNOLOGY) | USB4110-GF-A |  |  | 640-USB4110-GF-A | https://www.mouser.co.uk/ProductDetail/GCT/USB4110-GF-A?qs=KUoIvG%2F9IlYiZvIXQjyJeA%3D%3D |  |  |  |  |  |  |  |  |  | https://componentsearchengine.com/part-view/USB4110-GF-A/GCT%20(GLOBAL%20CONNECTOR%20TECHNOLOGY) |  |  |  |  |  |  |  | ,,,,,,,,,,,,,,,,
1 | SI1308EDL-T1-GE3 | SI1308EDL-T1-GE3 | SOT65P210X110-3N | Q2 | MOSFET N-Ch 30V 1.5A TrenchFET SC70 Vishay Si1308EDL-T1-GE3 N-channel MOSFET Transistor, 1.5 A, 30 V, 3-Pin SC-70 |  |  | In Stock |  | https://www.snapeda.com/parts/SI1308EDL-T1-GE3/Vishay+Siliconix/view-part/?ref=eda |  |  | Si1308EDL-T1-GE3 N-channel MOSFET Transistor | 1.5 A | 30 V | 3-Pin SC-70 | Siliconix / Vishay SI1308EDL-T1-GE3 |  |  |  |  |  |  | Vishay Siliconix |  |  |  |  |  | SI1308EDL-T1-GE3 |  | SOT-323 Vishay Semiconductor |  | https://componentsearchengine.com/part-view/DMG2305UX-7/Diodes%20Incorporated | None |  | https://www.snapeda.com/api/url_track_click_mouser/?unipart_id=274603&manufacturer=Vishay Siliconix&part_name=SI1308EDL-T1-GE3&search_term=None |  | https://www.snapeda.com/parts/SI1308EDL-T1-GE3/Vishay+Siliconix/view-part/?ref=snap |  |  | ,,,,,,,,,,,,,
17 | TPTP20R | TPTP20R | TP20R | TP1, TP2, TP3, TP4, TP5, TP6, TP7, TP8, TP9, TP10, TP11, TP12, TP13, TP14, TP15, TP16, TP17 | Test pad |  |  |  |  |  |  |  |  |  |  |  |  |  |  |  |  |  |  |  |  |  |  |  | 2 |  |  |  | https://grabcad.com/library/test-points-printed-circuit-board-1
1 | USBLC6-2SC6Y | USBLC6-2SC6Y | SOT95P280X145-6N | D1 | Low Cap. ESD Protection Auto SOT-23-6 STMicroelectronics USBLC6-2SC6Y, Dual Uni-Directional TVS Diode Array, 6-Pin SOT-23 |  |  | In Stock |  | https://www.snapeda.com/parts/USBLC6-2SC6Y/STMicroelectronics/view-part/?ref=eda |  |  | 17V Clamp 5A (8/20µs) Ipp Tvs Diode Surface Mount SOT-23-6 |  |  |  |  |  |  | STMicroelectronics |  |  |  |  |  | USBLC6-2SC6Y |  | SOT-23-6 STMicroelectronics |  |  | None |  | https://www.snapeda.com/parts/USBLC6-2SC6Y/STMicroelectronics/view-part/?ref=eda |  | https://www.snapeda.com/parts/USBLC6-2SC6Y/STMicroelectronics/view-part/?ref=snap |  |  |  |  |  | ,,,,,,,,,,,,,,
1 | W25Q512JVEIQ | W25Q512JVEIQ | SON127P600X800X80-9N | U1 | Check availability |  |  | In Stock |  | https://www.snapeda.com/parts/W25Q512JVEIQ/Winbond+Electronics/view-part/?ref=eda |  |  | FLASH - NOR Memory IC 512Mb (64M x 8) SPI - Quad I/O 133 MHz 8-WSON (8x6) |  |  |  |  |  |  | Winbond Electronics |  |  |  |  |  | W25Q512JVEIQ |  | Package |  |  | None |  | https://www.snapeda.com/parts/W25Q512JVEIQ/Winbond+Electronics/view-part/?ref=eda |  | https://www.snapeda.com/parts/W25Q512JVEIQ/Winbond+Electronics/view-part/?ref=snap |  |  |  |  |  | ,,,,,,,,,,,,,,,,
1 | XC6220A331MR-G | XC6220A331MR-G | SOT95P280X120-5N | IC4 | LDO Voltage Regulators |  |  |  |  |  |  |  | LDO Voltage Regulators |  |  | 1.2mm |  | Torex | XC6220A331MR-G |  |  | 865-XC6220A331MR-G | https://www.mouser.co.uk/ProductDetail/Torex-Semiconductor/XC6220A331MR-G?qs=AsjdqWjXhJ8ZSWznL1J0gg%3D%3D |  |  |  |  |  |  |  |  |  | https://componentsearchengine.com/part-view/XC6220A331MR-G/Torex |  |  |  |  |  |  |  | ,,,,,,,,,,,,,,,,

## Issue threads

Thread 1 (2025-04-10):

[SCHEMATIC] - Lipsa nume semnale pentru TP

catalinabuduran, 2025-04-10:
Test pad-urile nu sunt marcate in silkscreen cu numele semnalelor pe care le poarta, ceea ce le face greu de identificat la debugging.
Adauga etichete clare pe silkscreen langa fiecare test pad, cu numele semnalului respectiv(ex. MISO, MOSI, etc.)

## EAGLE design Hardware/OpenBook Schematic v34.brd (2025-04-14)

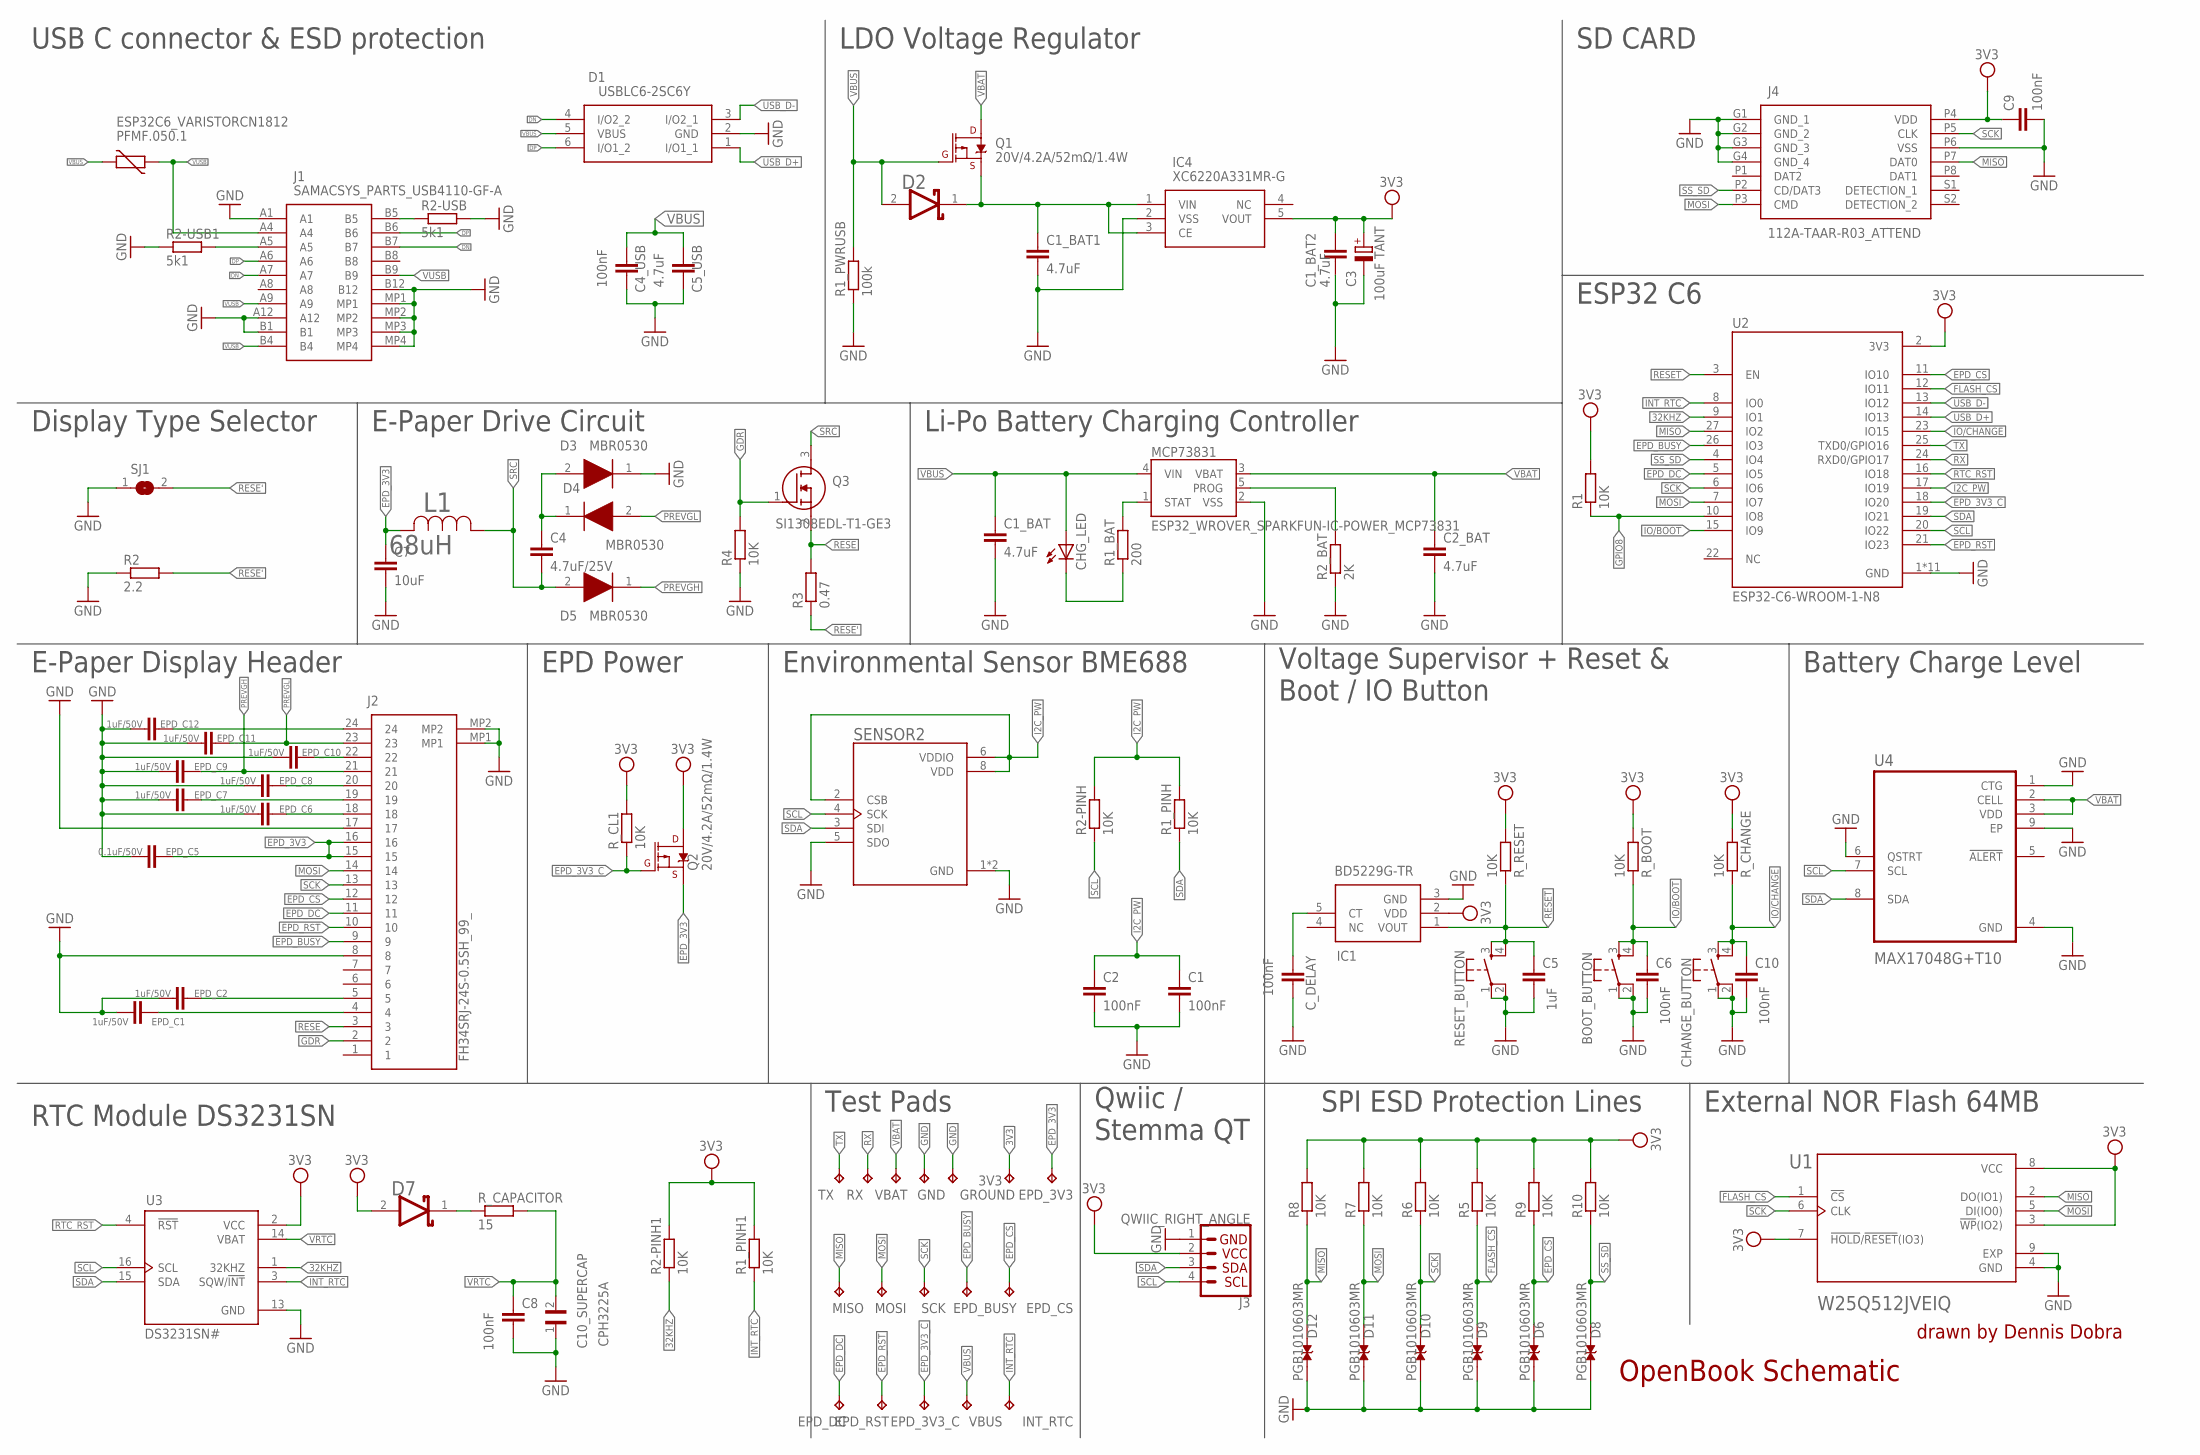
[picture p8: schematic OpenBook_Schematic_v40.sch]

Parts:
3V3: TPTP20R; TP20R
BOOT_BUTTON: BUTTON_CUSYOMV1; MYBUTTON
C1, C2, C4_USB, C6, C8, C9, C10: 100nF; EAGLE-LTSPICE_C0402
C1_BAT, C1_BAT1, C1_BAT2, C2_BAT, C5_USB: 4.7uF; EAGLE-LTSPICE_C0402
C3: 100uF TANT; RCL_CT3528
C4: 4.7uF/25V; EAGLE-LTSPICE_C0402
C5: 1uF; EAGLE-LTSPICE_C0402
C7: 10uF; EAGLE-LTSPICE_C0402
C10_SUPERCAP: CPH3225A; CAPCP3225X100N
CHANGE_BUTTON: BUTTON_CUSYOMV1; MYBUTTON
CHG_LED: ADAFRUIT_LEDCHIP-LED0603; ADAFRUIT_CHIP-LED0603
C_DELAY: 100nF; EAGLE-LTSPICE_C0402
D1: USBLC6-2SC6Y; SOT95P280X145-6N
D2, D7: ESP32_WROVER_AVX---SD0805S020S1R0_AVX_SD0805S020S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; ESP32_WROVER_AVX---SD0805S020S1R0_AVX_SD0805S020S1R0_0
D3, D4, D5: MBR0530; SOD3716X135N
D6, D8, D9, D10, D11, D12: PGB1010603MR; DIOC1608X36N
EPD_3V3, EPD_3V3_C: TPTP20R; TP20R
EPD_BUSY: TPTP20R; TP20R
EPD_C1, EPD_C2, EPD_C6, EPD_C7, EPD_C8, EPD_C9, EPD_C10, EPD_C11, EPD_C12: 1uF/50V; EAGLE-LTSPICE_C0402
EPD_C5: 0.1uF/50V; EAGLE-LTSPICE_C0402
EPD_CS: TPTP20R; TP20R
EPD_DC: TPTP20R; TP20R
EPD_RST: TPTP20R; TP20R
GND: TPTP20R; TP20R
GROUND: TPTP20R; TP20R
IC1: BD5229G-TR; SOT95P280X125-5N
IC4: XC6220A331MR-G; SOT95P280X120-5N
INT_RTC: TPTP20R; TP20R
J1: SAMACSYS_PARTS_USB4110-GF-A; SAMACSYS_PARTS_USB4110GFA
J2: FH34SRJ-24S-0.5SH_99_; FH34SRJ24S05SH99
J3: QWIIC_RIGHT_ANGLE; JST04_1MM_RA
J4: 112A-TAAR-R03_ATTEND; 112ATAARR03ATTEND
L1: 68uH; IND_4828-WE-TPC_WRE
MCP73831: ESP32_WROVER_SPARKFUN-IC-POWER_MCP73831; ESP32_WROVER_SPARKFUN-IC-POWER_SOT23-5
MISO: TPTP20R; TP20R
MOSI: TPTP20R; TP20R
PFMF.050.1: ESP32C6_VARISTORCN1812; ESP32C6_VARISTOR_CT/CN1812
Q1, Q2: 20V/4.2A/52mΩ/1.4W; ESP32_WROVER_SPARKFUN-DISCRETESEMI_SOT23-3
Q3: SI1308EDL-T1-GE3; SOT65P210X110-3N
R1, R1_PINH, R1_PINH1, R2-PINH, R2-PINH1, R4, R5, R6, R7, R8, R9, R10: 10K; ESP32_WROVER_EAGLE-LTSPICE_R0402
R1_BAT: 200; ESP32_WROVER_EAGLE-LTSPICE_R0402
R1_PWRUSB: 100k; ESP32_WROVER_EAGLE-LTSPICE_R0402
R2: 2.2; ESP32_WROVER_EAGLE-LTSPICE_R0402
R2-USB, R2-USB1: 5k1; ESP32_WROVER_EAGLE-LTSPICE_R0402
R2_BAT: 2K; ESP32_WROVER_EAGLE-LTSPICE_R0402
R3: 0.47; ESP32_WROVER_EAGLE-LTSPICE_R0402
RESET_BUTTON: BUTTON_CUSYOMV1; MYBUTTON
RX: TPTP20R; TP20R
R_BOOT: 10K; ESP32_WROVER_EAGLE-LTSPICE_R0402
R_CAPACITOR: 15; ESP32_WROVER_EAGLE-LTSPICE_R0402
R_CHANGE: 10K; ESP32_WROVER_EAGLE-LTSPICE_R0402
R_CL1: 10K; ESP32_WROVER_EAGLE-LTSPICE_R0402
R_RESET: 10K; ESP32_WROVER_EAGLE-LTSPICE_R0402
SCK: TPTP20R; TP20R
SENSOR2: ESP32_WROVER_BME680_BME680; ESP32_WROVER_BME680_PSON80P300X300X100-8N
SJ1: SJ
TX: TPTP20R; TP20R
U1: W25Q512JVEIQ; SON127P600X800X80-9N
U2: ESP32-C6-WROOM-1-N8; XCVR_ESP32-C6-WROOM-1-N8
U3: DS3231SN#; SOIC127P1032X265-16N
U4: MAX17048G+T10; SON50P200X200X80-9N
VBAT: TPTP20R; TP20R
VBUS: TPTP20R; TP20R

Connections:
3V3: 3V3.TP, C1_BAT2.1, C3.+, C9.1, D7.2 (ANODE), IC1.2 (VDD), IC4.5 (VOUT), J3.2, J4.P4 (VDD), Q2.3 (D), R1.2, R1_PINH1.2, R2-PINH1.2, R5.2, R6.2, R7.2, R8.2, R9.2, R10.2, R_BOOT.2, R_CHANGE.2, R_CL1.2, R_RESET.2, U1.3 (!WP!(IO2)), U1.7 (!HOLD!/!RESET!(IO3)), U1.8 (VCC), U2.2 (3V3), U3.2 (VCC)
32KHZ: R2-PINH1.1, U2.9 (IO1), U3.1 (32KHZ)
DN: D1.4 (I/O2_2), J1.A7, J1.B7
DP: D1.6 (I/O1_2), J1.A6, J1.B6
EPD_3V3: C7.1, EPD_3V3.TP, EPD_C5.2, J2.15, J2.16, L1.2, Q2.2 (S)
EPD_3V3_C: EPD_3V3_C.TP, Q2.1 (G), R_CL1.1, U2.18 (IO20)
EPD_BUSY: EPD_BUSY.TP, J2.9, U2.26 (IO3)
EPD_CS: D6.2, EPD_CS.TP, J2.12, R9.1, U2.11 (IO10)
EPD_DC: EPD_DC.TP, J2.11, U2.5 (IO5)
EPD_RST: EPD_RST.TP, J2.10, U2.21 (IO23)
FLASH_CS: D9.2, R5.1, U1.1 (!CS), U2.12 (IO11)
GDR: J2.2, Q3.1 (G), R4.2
GND: BOOT_BUTTON.1, BOOT_BUTTON.2, C1.2, C1_BAT.2, C1_BAT1.2, C1_BAT2.2, C2.2, C2_BAT.2, C3.-, C4_USB.2, C5.2, C5_USB.2, C6.2, C7.2, C8.2, C9.2, C10.2, C10_SUPERCAP.1, CHANGE_BUTTON.1, CHANGE_BUTTON.2, C_DELAY.2, D1.2 (GND), D3.1 (K), D6.1, D8.1, D9.1, D10.1, D11.1, D12.1, EPD_C1.1, EPD_C2.1, EPD_C5.1, EPD_C6.1, EPD_C7.1, EPD_C8.1, EPD_C9.1, EPD_C10.1, EPD_C11.1, EPD_C12.1, GND.TP, GROUND.TP, IC1.3 (GND), IC4.2 (VSS), J1.A1, J1.A12, J1.B1, J1.B12, J1.MP1, J1.MP2, J1.MP3, J1.MP4, J2.8, J2.17, J2.MP1, J2.MP2, J3.1, J4.G1 (GND_1), J4.G2 (GND_2), J4.G3 (GND_3), J4.G4 (GND_4), J4.P6 (VSS), MCP73831.2 (VSS), R1_PWRUSB.1, R2.1, R2-USB.2, R2-USB1.1, R2_BAT.1, R4.1, RESET_BUTTON.1, RESET_BUTTON.2, SENSOR2.1 (GND), SENSOR2.5 (SDO), SENSOR2.7 (GND), SJ1.1, U1.4 (GND), U1.9 (EXP), U2.1 (GND), U2.28 (GND), U2.29_1 (GND), U2.29_2 (GND), U2.29_3 (GND), U2.29_4 (GND), U2.29_5 (GND), U2.29_6 (GND), U2.29_7 (GND), U2.29_8 (GND), U2.29_9 (GND), U3.13 (GND), U4.1 (CTG), U4.4 (GND), U4.6 (QSTRT), U4.9 (EP)
GPIO8: R1.1, U2.10 (IO8)
I2C_PW: C1.1, C2.1, R1_PINH.2, R2-PINH.2, SENSOR2.2 (CSB), SENSOR2.6 (VDDIO), SENSOR2.8 (VDD), U2.17 (IO19)
INT_RTC: INT_RTC.TP, R1_PINH1.1, U2.8 (IO0), U3.3 (SQW/!INT)
IO/BOOT: BOOT_BUTTON.3, BOOT_BUTTON.4, C6.1, R_BOOT.1, U2.15 (IO9)
IO/CHANGE: C10.1, CHANGE_BUTTON.3, CHANGE_BUTTON.4, R_CHANGE.1, U2.23 (IO15)
MISO: D12.2, J4.P7 (DAT0), MISO.TP, R8.1, U1.2 (DO(IO1)), U2.27 (IO2)
MOSI: D11.2, J2.14, J4.P3 (CMD), MOSI.TP, R7.1, U1.5 (DI(IO0)), U2.7 (IO7)
unnamed: MCP73831.1 (STAT), R1_BAT.2
unnamed: C1_BAT1.1, D2.1 (CATHODE), IC4.1 (VIN), IC4.3 (CE), Q1.2 (S)
unnamed: CHG_LED.C, R1_BAT.1
unnamed: MCP73831.5 (PROG), R2_BAT.2
unnamed: D7.1 (CATHODE), R_CAPACITOR.1
unnamed: C_DELAY.1, IC1.5 (CT)
unnamed: J1.A5, R2-USB1.2
unnamed: C4.1, D3.2 (A), D4.1 (K)
unnamed: EPD_C1.2, J2.4
unnamed: J1.B5, R2-USB.1
unnamed: EPD_C2.2, J2.5
unnamed: EPD_C10.2, J2.22
unnamed: EPD_C12.2, J2.24
unnamed: EPD_C7.2, J2.19
unnamed: EPD_C8.2, J2.20
unnamed: EPD_C6.2, J2.18
PREVGH: D5.1 (K), EPD_C9.2, J2.21
PREVGL: D4.2 (A), EPD_C11.2, J2.23
RESE: J2.3, Q3.2 (S), R3.2
RESE': R2.2, R3.1, SJ1.2
RESET: C5.1, IC1.1 (VOUT), RESET_BUTTON.3, RESET_BUTTON.4, R_RESET.1, U2.3 (EN)
RTC_RST: U2.16 (IO18), U3.4 (!RST)
RX: RX.TP, U2.24 (RXD0/GPIO17)
SCK: D10.2, J2.13, J4.P5 (CLK), R6.1, SCK.TP, U1.6 (CLK), U2.6 (IO6)
SCL: J3.4, R2-PINH.1, SENSOR2.4 (SCK), U2.20 (IO22), U3.16 (SCL), U4.7 (SCL)
SDA: J3.3, R1_PINH.1, SENSOR2.3 (SDI), U2.19 (IO21), U3.15 (SDA), U4.8 (SDA)
SRC: C4.2, D5.2 (A), L1.1, Q3.3 (D)
SS_SD: D8.2, J4.P2 (CD/DAT3), R10.1, U2.4 (IO4)
TX: TX.TP, U2.25 (TXD0/GPIO16)
USB_D+: D1.1 (I/O1_1), U2.14 (IO13)
USB_D-: D1.3 (I/O2_1), U2.13 (IO12)
VBAT: C2_BAT.1, MCP73831.3 (VBAT), Q1.3 (D), U4.2 (CELL), U4.3 (VDD), VBAT.TP
VBUS: C1_BAT.1, C4_USB.1, C5_USB.1, CHG_LED.A, D1.5 (VBUS), D2.2 (ANODE), MCP73831.4 (VIN), PFMF.050.1.2, Q1.1 (G), R1_PWRUSB.2, VBUS.TP
VRTC: C8.1, C10_SUPERCAP.2, R_CAPACITOR.2, U3.14 (VBAT)
VUSB: J1.A4, J1.A9, J1.B4, J1.B9, PFMF.050.1.1

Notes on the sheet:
USB C connector & ESD protection
SD CARD
LDO Voltage Regulator
Display Type Selector
E-Paper Drive Circuit
Li-Po Battery Charging Controller
ESP32 C6
E-Paper Display Header
EPD Power
Environmental Sensor BME688
Voltage Supervisor + Reset & Boot / IO Button
Battery Charge Level
RTC Module DS3231SN
Test Pads
Qwiic / Stemma QT
SPI ESD Protection Lines
External NOR Flash 64MB
OpenBook Schematic
drawn by Dennis Dobra

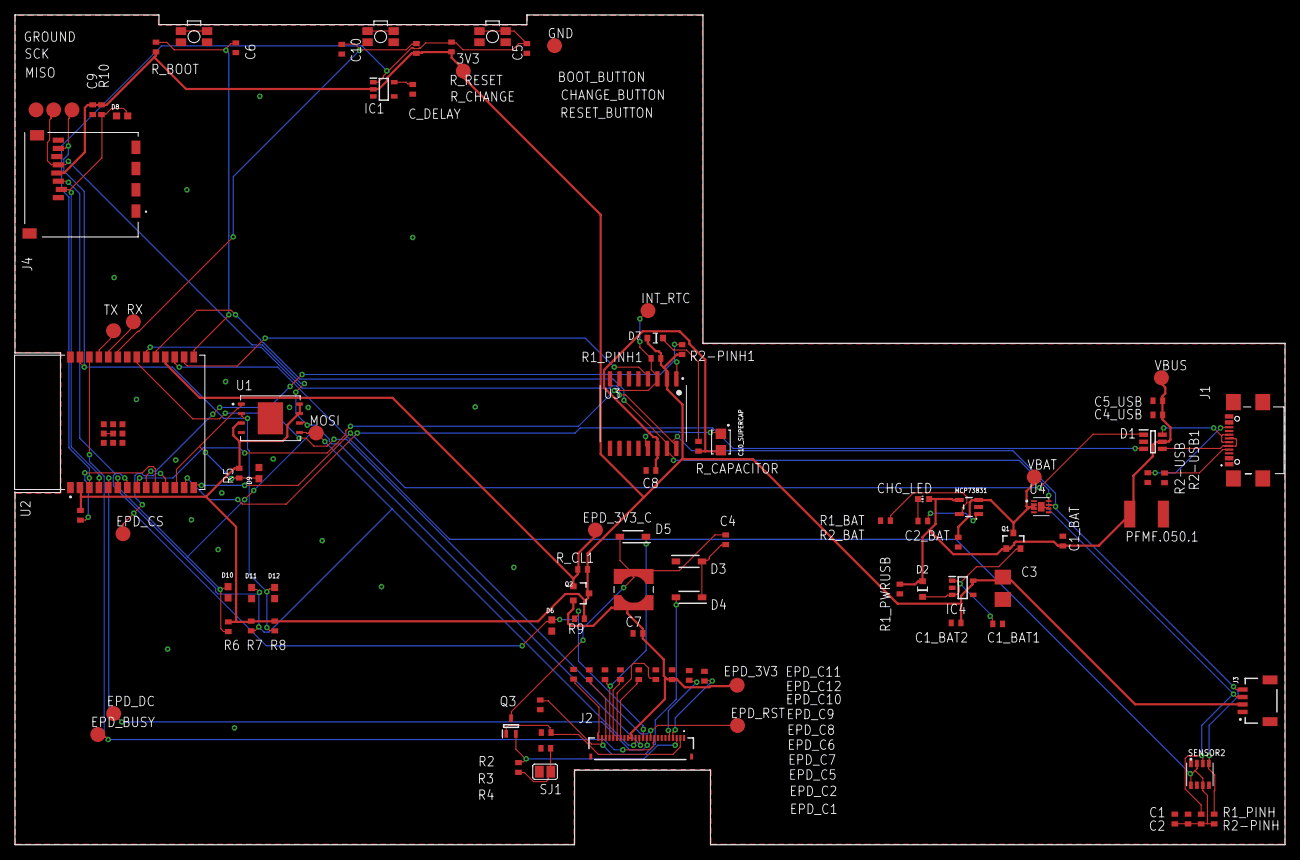
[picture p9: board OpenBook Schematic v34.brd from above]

Board: 2 copper layers, 170.2 x 111.2 mm, 103 parts (0 on the bottom side), 55 nets.

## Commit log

2025-04-06 OpenBook Project completed
    [OpenBook 2D PCB v31.brd, OpenBook_Schematic_v38.sch, PnP_OpenBook Schematic v31_front.csv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]
2025-04-06 update BOM and PnP files
    [BOM_File.csv, PnP_File.csv]
2025-04-14 corrected the raised issues
    [OpenBook 2D PCB v31.brd, OpenBook Schematic v34.brd, OpenBook_Schematic_v38.sch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]

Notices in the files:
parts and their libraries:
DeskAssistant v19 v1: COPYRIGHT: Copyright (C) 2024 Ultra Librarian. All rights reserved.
